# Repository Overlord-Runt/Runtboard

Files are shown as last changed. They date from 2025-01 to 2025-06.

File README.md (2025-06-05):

# Runtboard - The custom keyboard made by Taran Mittal/Overlord Runt
\
\
\
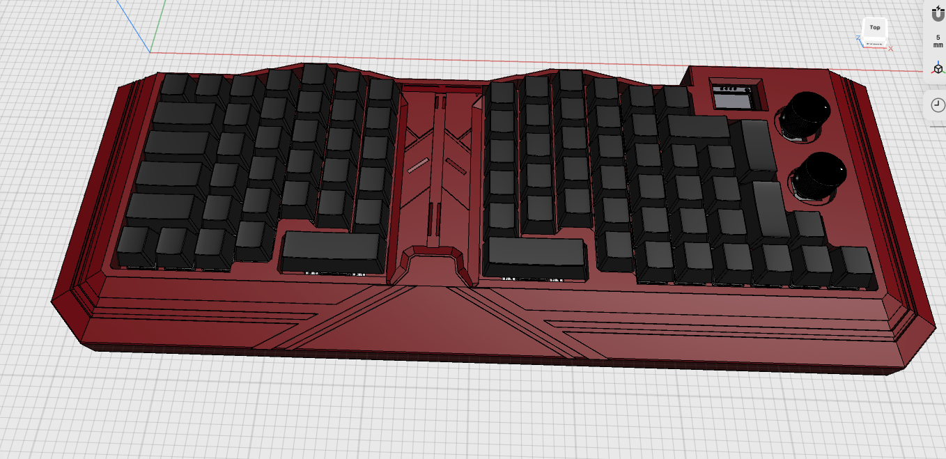
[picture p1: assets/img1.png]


## What this is
The Runtboard is a custom keyboard that I designed and coded. It has 83 keys, 2 encoders, 17 LEDs, and an OLED SSD1306 screen. I designed it to have a split keyboard style with keys split down the middle but intentionally left it stuck together to have easier firmware.\
\
I spent a total of rougly 70 hours on this project, from intial designs, pcb, case, and finally firmware. Before reaching this final design, I went through about 3 different variations going back and forth with the pcb and case.\
The Runtboard has 2 layers, one with your regular keyboard layout and one that changes the functions of the encoders. I hope you like the design and you are free to make it yourself if you have a big enough 3d printer.

## Schematic
### Here are the images for my schematic
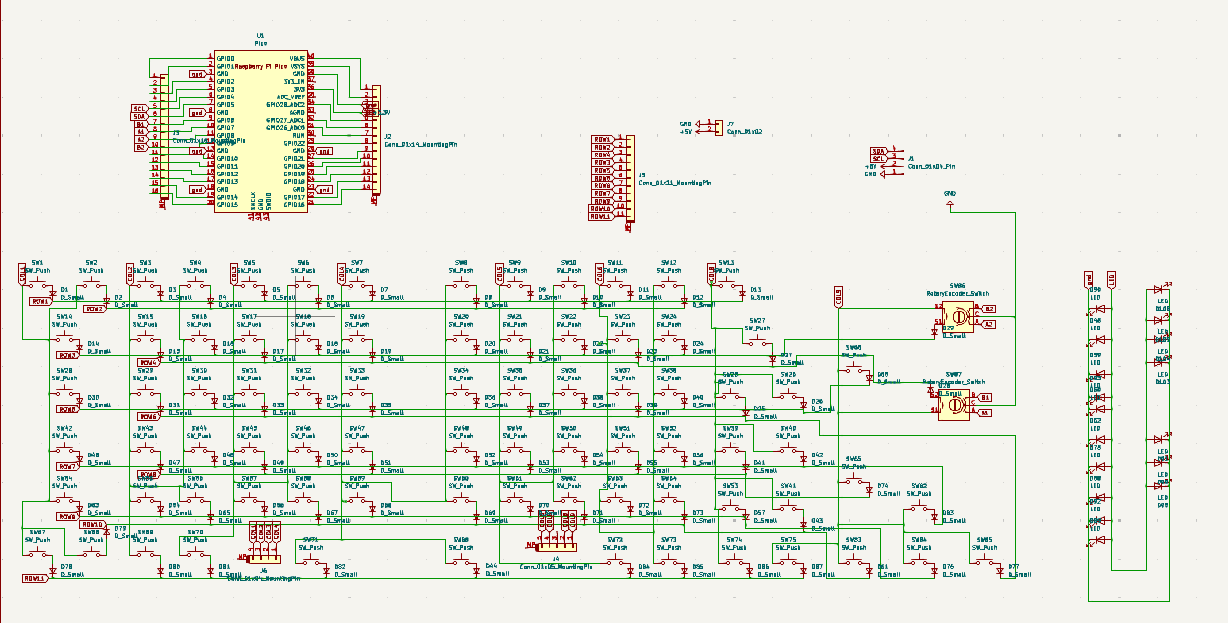
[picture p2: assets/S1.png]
\
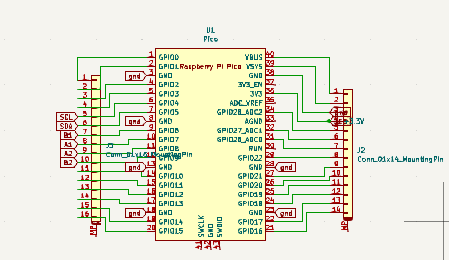
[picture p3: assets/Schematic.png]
\
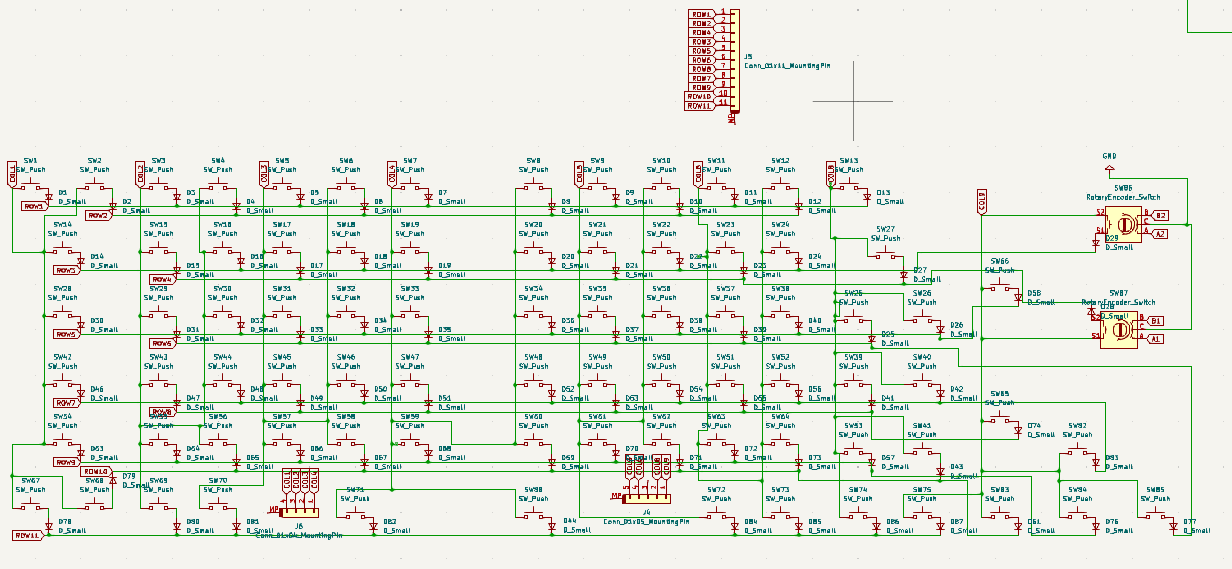
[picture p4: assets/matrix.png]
\
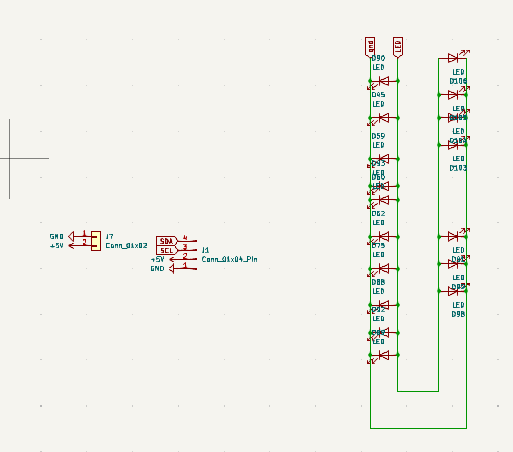
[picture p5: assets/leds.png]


The header pins are there to make it easier for my wires to reach the pico without having to do funny stuff with the routing and microcontroller. It in a way gives me a third layer to use for connections, which made my life way easier when designing this board.

### The Matrix
You may notice that my matrix looks a bit funny. This is because I overcomplicated it in order to give myself an extra 2 pins to use. By removing 8 columns and adding 6 rows, I gave myself an extra 2 pins that I used to add an extra encoder.

## PCB
### Here are images for my pcb
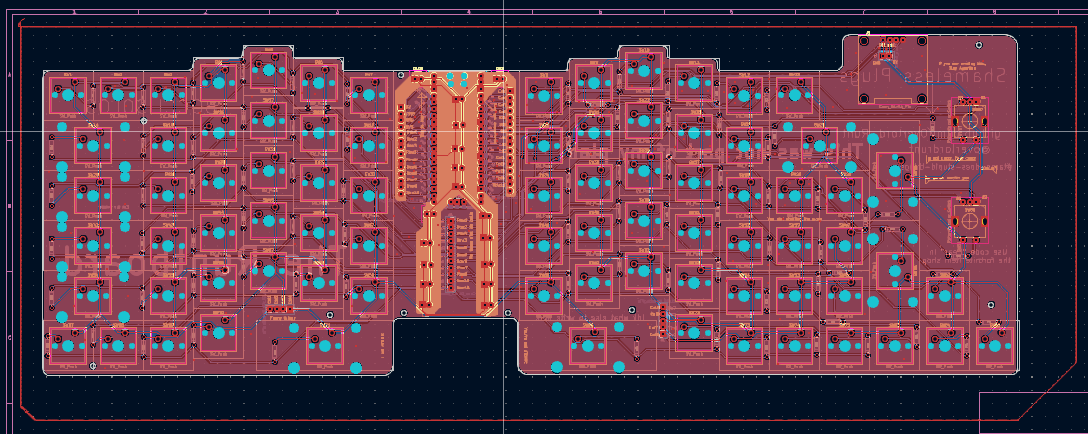
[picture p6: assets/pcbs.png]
\
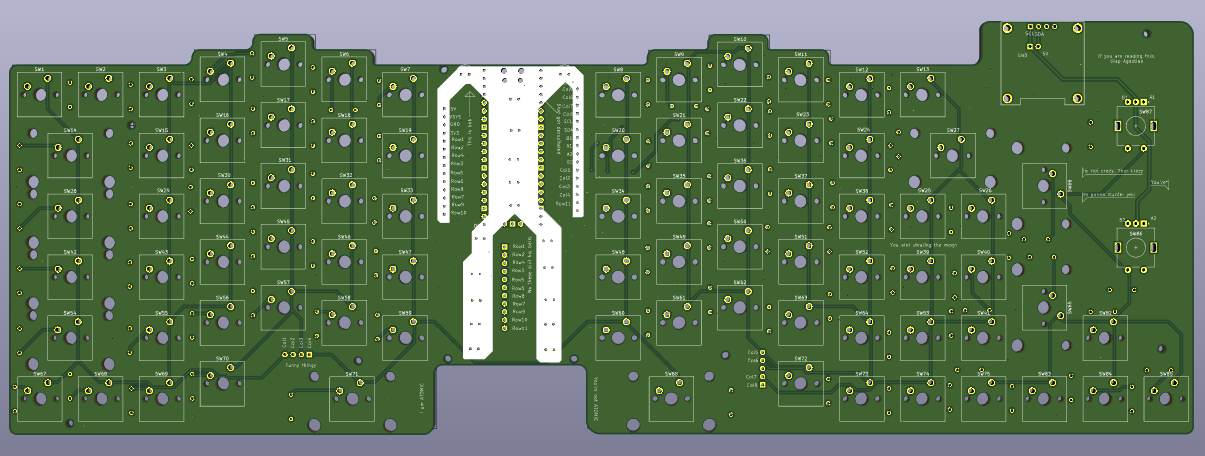
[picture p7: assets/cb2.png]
\
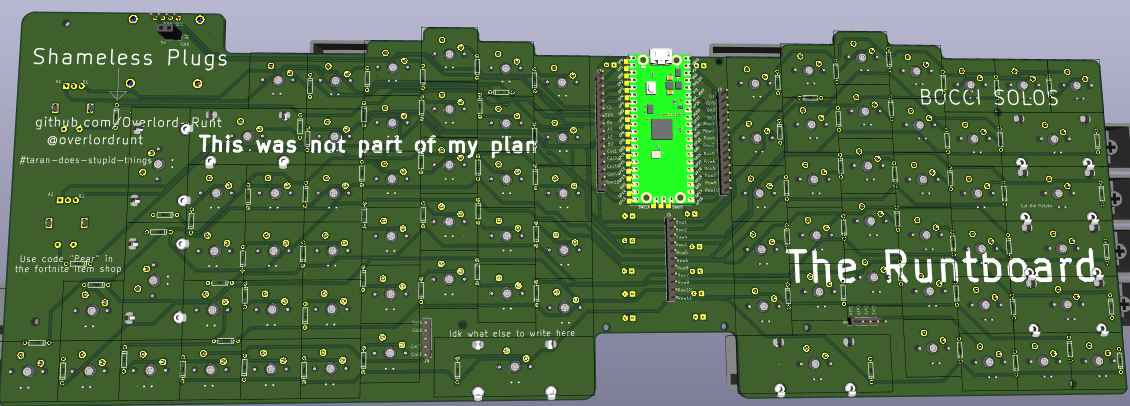
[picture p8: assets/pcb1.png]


This is what my pcb looks like. It has a basic silkscreen but i drew all of it on kicad no figma or anything.

### Silkscreen Stuff
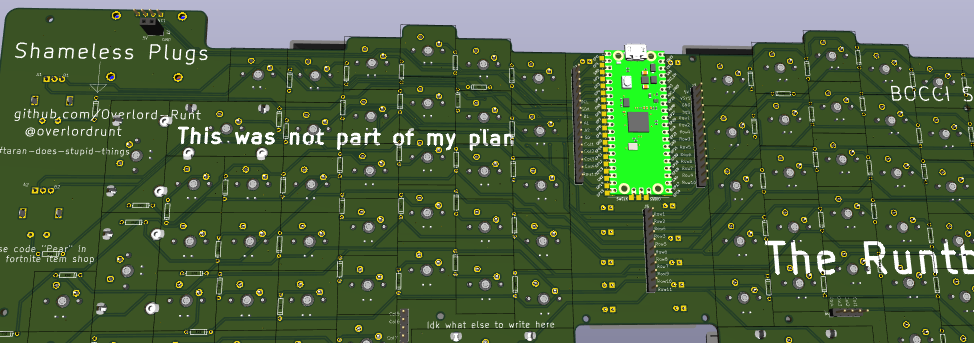
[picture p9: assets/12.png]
\
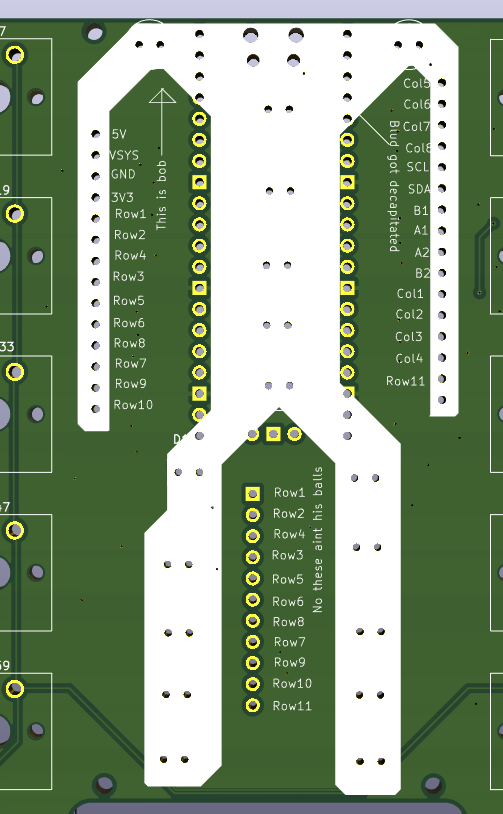
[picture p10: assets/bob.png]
\
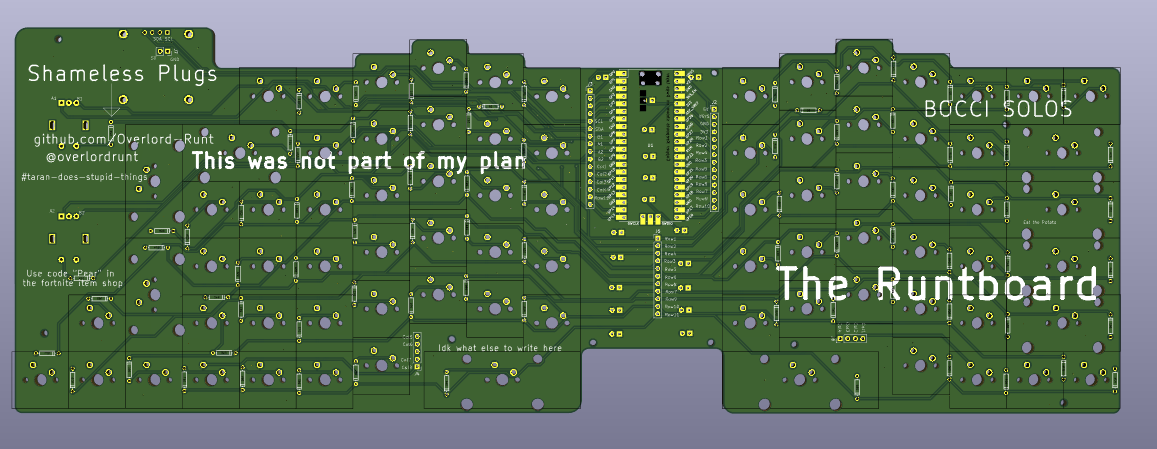
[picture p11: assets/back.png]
\
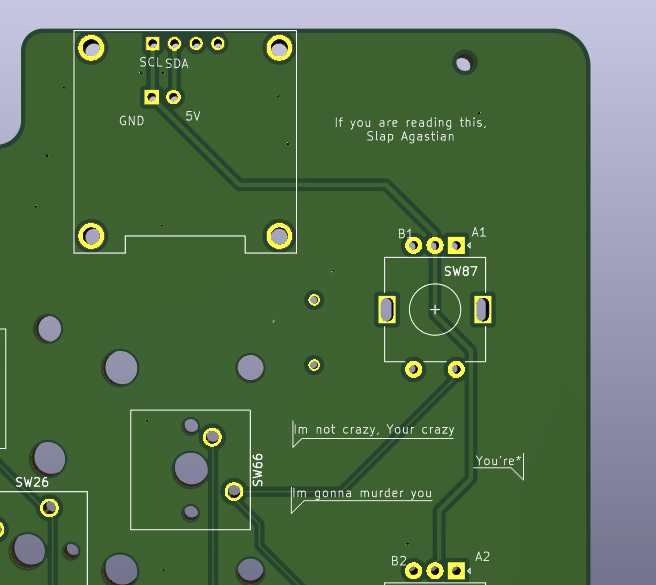
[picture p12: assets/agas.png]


On my silkscreen i have bob, the decapitated stick figure. I also have a bunch of anime references and some plugs of my socials and stuff. You should join #taran-does-stupid-things btw. its super cool. run /Darren in slack to join

## Case
I spent a lot of time designing my case(upward of 40 hours) and hope you like the design.

first\
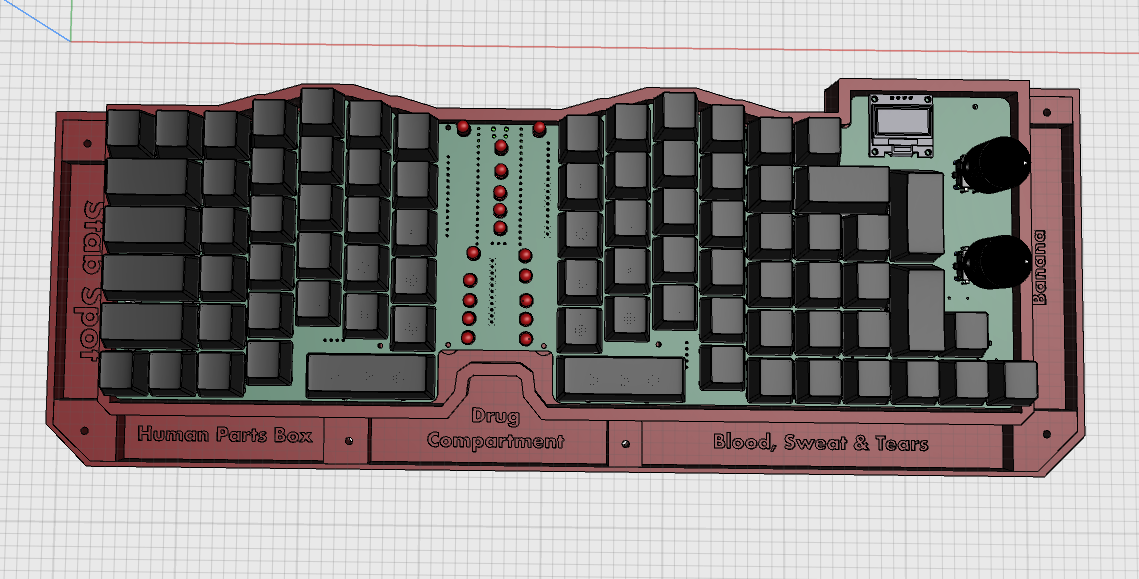
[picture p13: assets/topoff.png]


## Resources used:
Joe scotto Youtube channel\
Qmk Guides\
Ai03 plate generator\
keyboard layout editor

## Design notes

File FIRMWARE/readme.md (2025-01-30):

# handwired/runtboard

handwired/runtboard

*A short description of the keyboard/project*

* Keyboard Maintainer: [Taran Mittal](https://github.com/Overlord-Runt)
* Hardware Supported: *The PCBs, controllers supported*
* Hardware Availability: *Links to where you can find this hardware*

Make example for this keyboard (after setting up your build environment):

    make handwired/runtboard:default

Flashing example for this keyboard:

    make handwired/runtboard:default:flash

See the [build environment setup](https://docs.qmk.fm/#/getting_started_build_tools) and the [make instructions](https://docs.qmk.fm/#/getting_started_make_guide) for more information. Brand new to QMK? Start with our [Complete Newbs Guide](https://docs.qmk.fm/#/newbs).

## Bootloader

Enter the bootloader in 3 ways:

* **Bootmagic reset**: Hold down the key at (0,0) in the matrix (usually the top left key or Escape) and plug in the keyboard
* **Physical reset button**: Briefly press the button on the back of the PCB - some may have pads you must short instead
* **Keycode in layout**: Press the key mapped to `QK_BOOT` if it is available

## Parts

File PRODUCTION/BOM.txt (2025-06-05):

Bill of Materials for the Runtboard

 83 Cherry MX switches - $24.35/9.36 shipping - https://www.pccasegear.com/products/63447/gateron-g-pro-3-0-red-switch-set-110-pack-keychron
 166 hotswap sockets - $5
 85 diodes - $1.82
 2 ec11 rotary encoders - $3.24
 1 ssd1306 0.96" 128x64 oled screen - self supplied
 17 Orange 5mm LEDs - $1.21
 9 MX stabilisers - $9.36 - https://www.pccasegear.com/products/58528/akko-screw-in-stabiliser-white
 1 meter of wire - self supplied
 1 Orpheus Pico
 14 M3 X D5.0 X L6.0 Heatsets - $1.01
 8 6mm M3 screws - $1.55
 6 20mm M3 screws - $2.69
 1 USBc-USBc cable
 3D printed case - 3d printed - Dark Red
 1 PCB - $22.20/13.92 shipping
 74 1.0u Keycaps - 3d printed
 7 2.0u Keycaps - 3d printed
 2 2.75u Keycaps - 3d printed
 2 Encoder knobs - 3d printed
Total - $107.21

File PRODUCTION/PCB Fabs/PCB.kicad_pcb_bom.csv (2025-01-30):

Designator | Quantity | Value | Footprint | Package | MPN | DNP | Mount_Type | Description | Sim.Device | Sim.Pins
D1, D10, D11, D12, D13, D14, D15, D16, D17, D18, D19, D2, D20, D21, D22, D23, D24, D25, D26, D27, D28, D29, D3, D30, D31, D32, D33, D34, D35, D36, D37, D38, D39, D4, D40, D41, D42, D43, D44, D46, D47, D48, D49, D5, D50, D51, D52, D53, D54, D55, D56, D57, D58, D6, D61, D63, D64, D65, D66, D67, D68, D69, D7, D70, D71, D72, D73, D74, D76, D77, D78, D79, D8, D80, D81, D82, D83, D84, D85, D86, D87, D9 | 82 | D_Small | DIODE-1N4148 |  |  |  | tht | Diode, small symbol | D | 1=K 2=A
D103, D104, D105, D106, D45, D59, D60, D62, D75, D88, D89, D90, D91, D92, D93, D98, D99 | 17 | LED | LED_D5.0mm |  |  |  | tht | Light emitting diode
J1 | 1 | Conn_01x04_Pin | MODULE_DM-OLED096-636 |  |  |  | tht | Generic connector, single row, 01x04, script generated
J2 | 1 | Conn_01x14_MountingPin | PinHeader_1x14_P2.54mm_Vertical |  |  |  | tht | Generic connectable mounting pin connector, single row, 01x14, script generated (kicad-library-utils/schlib/autogen/connector/)
J3 | 1 | Conn_01x16_MountingPin | PinHeader_1x16_P2.54mm_Vertical |  |  |  | tht | Generic connectable mounting pin connector, single row, 01x16, script generated (kicad-library-utils/schlib/autogen/connector/)
J4 | 1 | Conn_01x05_MountingPin | PinHeader_1x05_P2.54mm_Vertical |  |  |  | tht | Generic connectable mounting pin connector, single row, 01x05, script generated (kicad-library-utils/schlib/autogen/connector/)
J5 | 1 | Conn_01x11_MountingPin | PinHeader_1x11_P2.54mm_Vertical |  |  |  | tht | Generic connectable mounting pin connector, single row, 01x11, script generated (kicad-library-utils/schlib/autogen/connector/)
J6 | 1 | Conn_01x04_MountingPin | PinHeader_1x04_P2.54mm_Vertical |  |  |  | tht | Generic connectable mounting pin connector, single row, 01x04, script generated (kicad-library-utils/schlib/autogen/connector/)
J7 | 1 | Conn_01x02 | PinSocket_1x02_P2.54mm_Vertical |  |  |  | tht | Generic connector, single row, 01x02, script generated (kicad-library-utils/schlib/autogen/connector/)
SW1, SW10, SW11, SW12, SW13, SW15, SW16, SW17, SW18, SW19, SW2, SW20, SW21, SW22, SW23, SW24, SW25, SW26, SW29, SW3, SW30, SW31, SW32, SW33, SW34, SW35, SW36, SW37, SW38, SW39, SW4, SW40, SW41, SW43, SW44, SW45, SW46, SW47, SW48, SW49, SW5, SW50, SW51, SW52, SW53, SW55, SW56, SW57, SW58, SW59, SW6, SW60, SW61, SW62, SW63, SW64, SW67, SW68, SW69, SW7, SW70, SW72, SW73, SW74, SW75, SW8, SW82, SW83, SW84, SW85, SW9 | 71 | SW_Push | SW_Cherry_MX_1.00u_PCB |  |  |  | tht | Push button switch, generic, two pins
SW14, SW27, SW28, SW42, SW54, SW65, SW66 | 7 | SW_Push | SW_Cherry_MX_2.00u_PCB |  |  |  | tht | Push button switch, generic, two pins
SW71, SW88 | 2 | SW_Push | SW_Cherry_MX_2.75u_PCB |  |  |  | tht | Push button switch, generic, two pins
SW86, SW87 | 2 | RotaryEncoder_Switch | RotaryEncoder_Alps_EC11E-Switch_Vertical_H20mm |  |  |  | tht | Rotary encoder, dual channel, incremental quadrate outputs, with switch
U1 | 1 | Pico | RPi_Pico_SMD_TH |  |  |  | tht

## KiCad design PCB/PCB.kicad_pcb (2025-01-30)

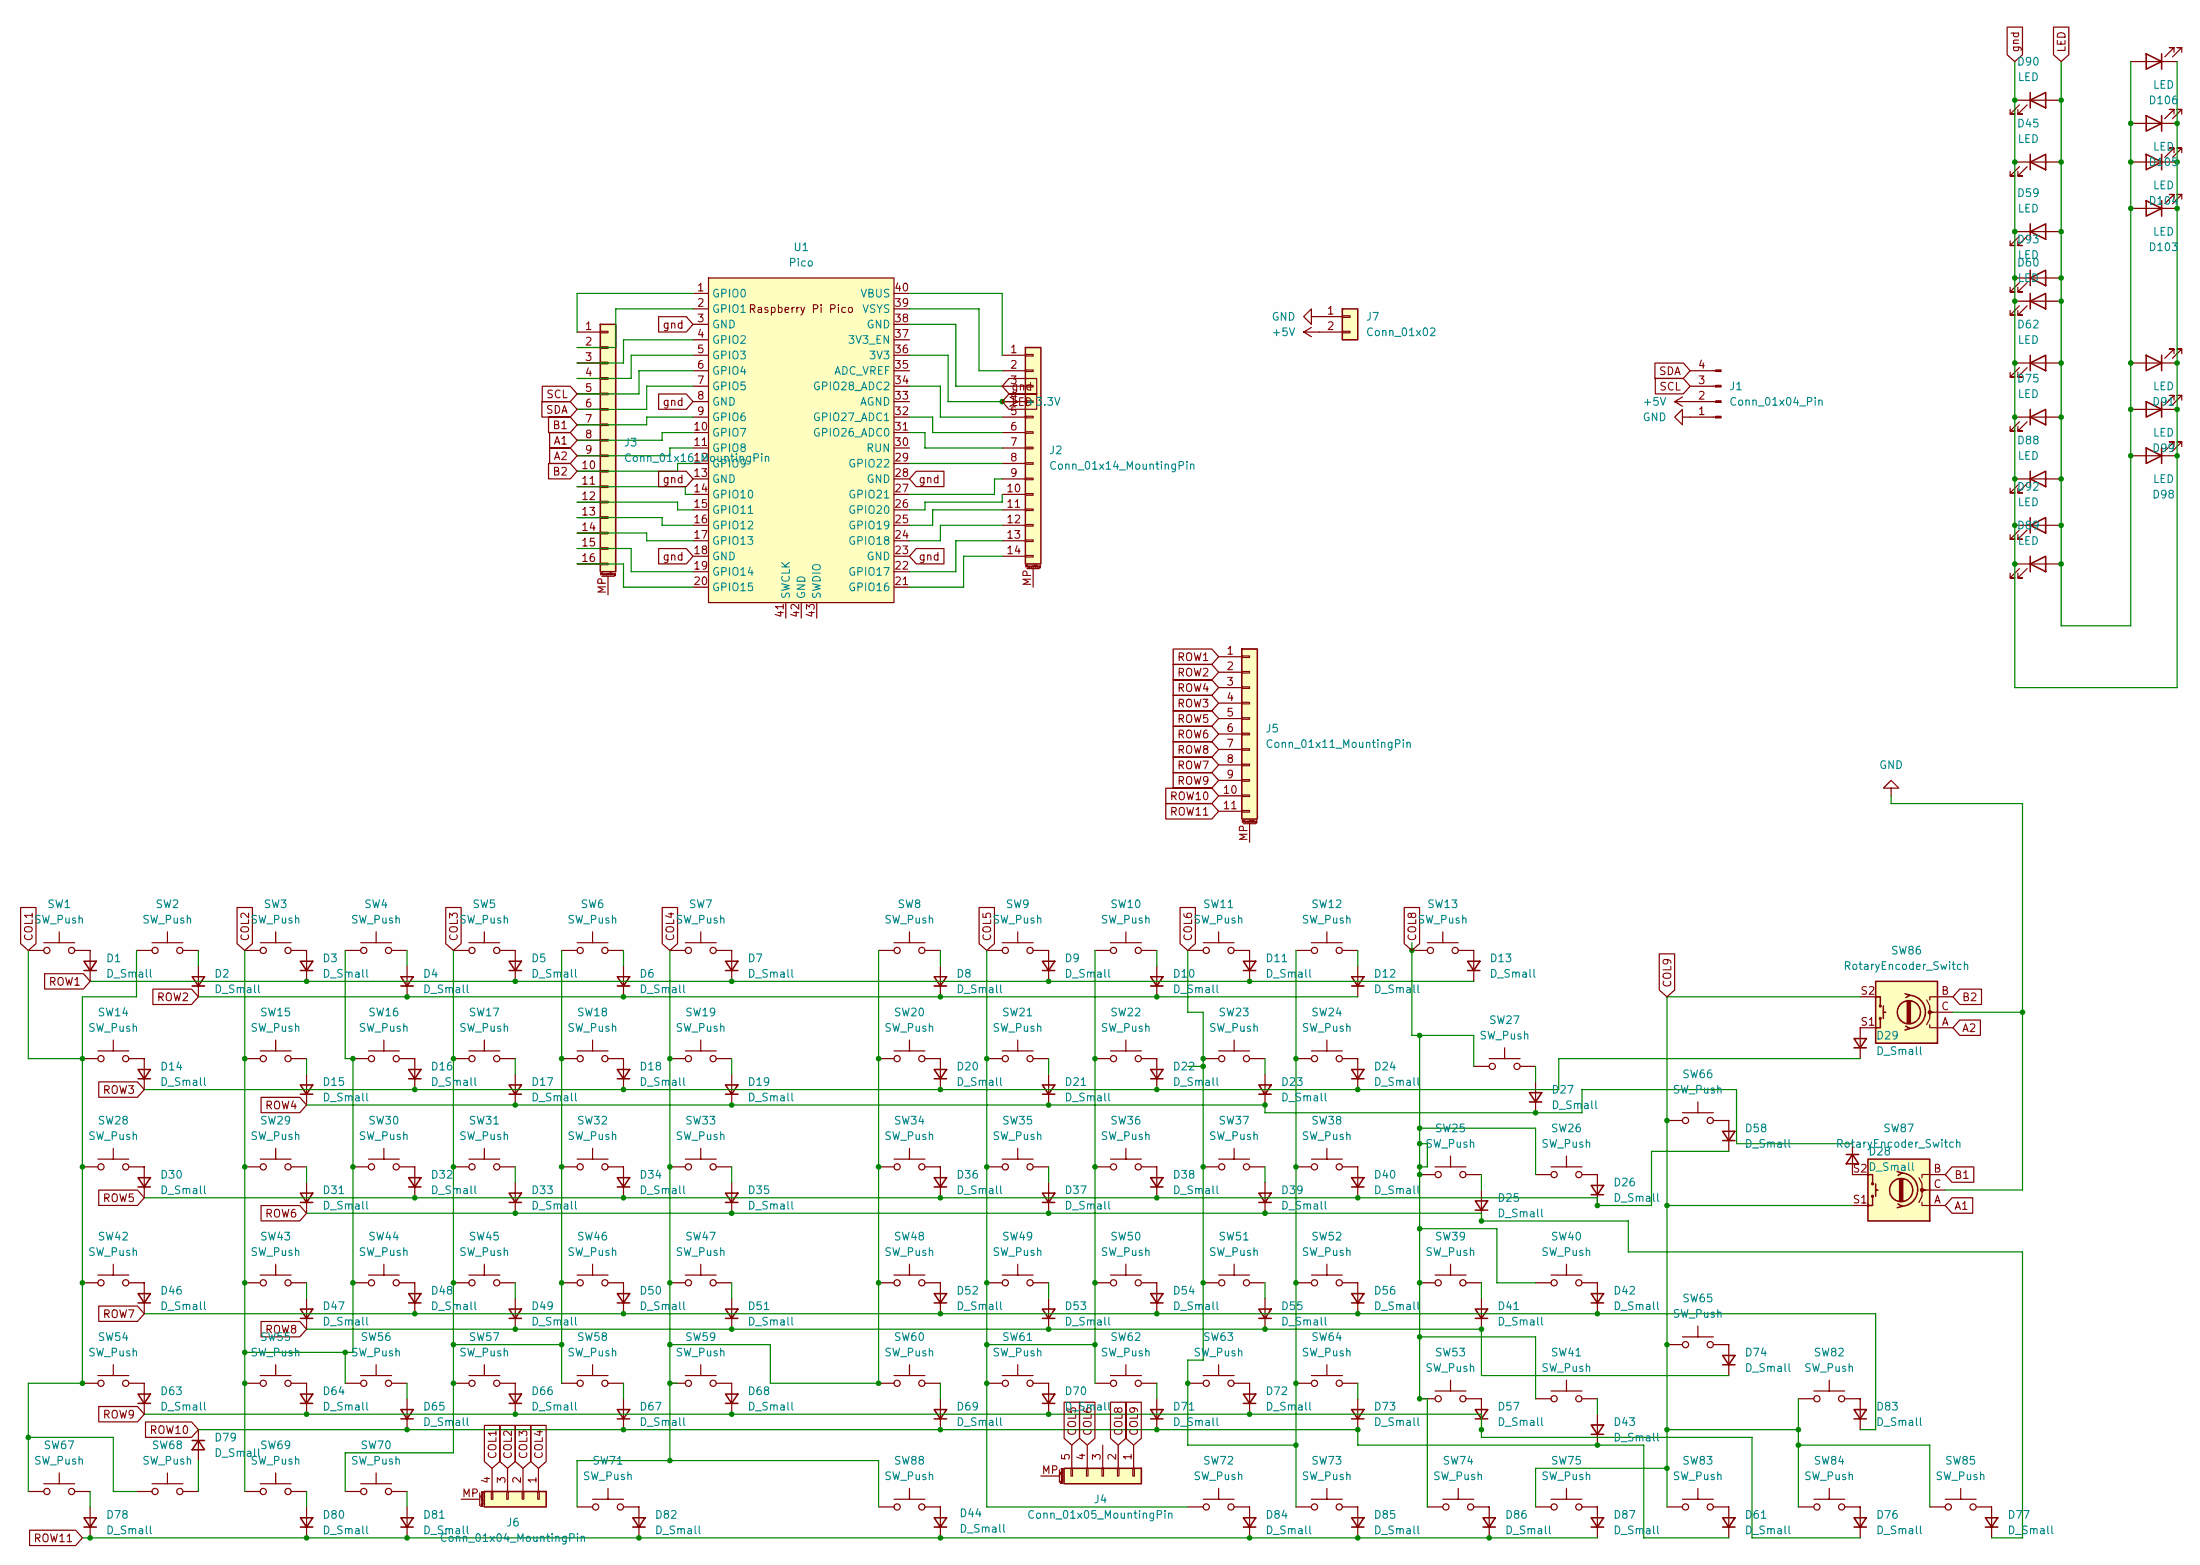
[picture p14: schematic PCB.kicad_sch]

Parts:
D1, D2, D3, D4, D5, D6, D7, D8, D9, D10, D11, D12, D13, D14, D15, D16, D17, D18, D19, D20, D21, D22, D23, D24, D25, D26, D27, D28, D29, D30, D31, D32, D33, D34, D35, D36, D37, D38, D39, D40, D41, D42, D43, D44, D46, D47, D48, D49, D50, D51, D52, D53, D54, D55, D56, D57, D58, D61, D63, D64, D65, D66, D67, D68, D69, D70, D71, D72, D73, D74, D76, D77, D78, D79, D80, D81, D82, D83, D84, D85, D86, D87: D_Small; DIODE-1N4148
D45, D59, D60, D62, D75, D88, D89, D90, D91, D92, D93, D98, D99, D103, D104, D105, D106: LED; LED_D5.0mm
J1: Conn_01x04_Pin; MODULE_DM-OLED096-636
J2: Conn_01x14_MountingPin; PinHeader_1x14_P2.54mm_Vertical
J3: Conn_01x16_MountingPin; PinHeader_1x16_P2.54mm_Vertical
J4: Conn_01x05_MountingPin; PinHeader_1x05_P2.54mm_Vertical
J5: Conn_01x11_MountingPin; PinHeader_1x11_P2.54mm_Vertical
J6: Conn_01x04_MountingPin; PinHeader_1x04_P2.54mm_Vertical
J7: Conn_01x02; PinSocket_1x02_P2.54mm_Vertical
SW1, SW2, SW3, SW4, SW5, SW6, SW7, SW8, SW9, SW10, SW11, SW12, SW13, SW15, SW16, SW17, SW18, SW19, SW20, SW21, SW22, SW23, SW24, SW25, SW26, SW29, SW30, SW31, SW32, SW33, SW34, SW35, SW36, SW37, SW38, SW39, SW40, SW41, SW43, SW44, SW45, SW46, SW47, SW48, SW49, SW50, SW51, SW52, SW53, SW55, SW56, SW57, SW58, SW59, SW60, SW61, SW62, SW63, SW64, SW67, SW68, SW69, SW70, SW72, SW73, SW74, SW75, SW82, SW83, SW84, SW85: SW_Push; SW_Cherry_MX_1.00u_PCB
SW14, SW27, SW28, SW42, SW54, SW65, SW66: SW_Push; SW_Cherry_MX_2.00u_PCB
SW71, SW88: SW_Push; SW_Cherry_MX_2.75u_PCB
SW86, SW87: RotaryEncoder_Switch; RotaryEncoder_Alps_EC11E-Switch_Vertical_H20mm
U1: Pico; RPi_Pico_SMD_TH

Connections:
+5V: J1.2, J7.2
A1: J3.8, SW87.A, U1.10 (GPIO7)
A2: J3.9, SW86.A, U1.11 (GPIO8)
B1: J3.7, SW87.B, U1.9 (GPIO6)
B2: J3.10, SW86.B, U1.12 (GPIO9)
COL1: J6.4, SW1.1, SW2.1, SW14.1, SW28.1, SW42.1, SW54.1, SW67.1, SW68.1
COL2: J6.3, SW3.1, SW4.1, SW15.1, SW16.1, SW29.1, SW30.1, SW43.1, SW44.1, SW55.1, SW56.1, SW69.1
COL3: J6.2, SW5.1, SW6.1, SW17.1, SW18.1, SW31.1, SW32.1, SW45.1, SW46.1, SW57.1, SW58.1, SW70.1
COL4: J6.1, SW7.1, SW8.1, SW19.1, SW20.1, SW33.1, SW34.1, SW47.1, SW48.1, SW59.1, SW60.1, SW71.1, SW88.1
COL5: J4.5, SW9.1, SW10.1, SW21.1, SW22.1, SW35.1, SW36.1, SW49.1, SW50.1, SW61.1, SW62.1, SW72.1
COL6: J4.4, SW11.1, SW12.1, SW23.1, SW24.1, SW37.1, SW38.1, SW51.1, SW52.1, SW63.1, SW64.1, SW73.1
COL8: J4.2, SW13.1, SW25.1, SW26.1, SW27.1, SW39.1, SW40.1, SW41.1, SW53.1, SW74.1
COL9: J4.1, SW65.1, SW66.1, SW75.1, SW82.1, SW83.1, SW84.1, SW85.1, SW86.S2, SW87.S1
GND: J1.1, J7.1, SW86.C, SW87.C
LED: D45.2 (A), D59.2 (A), D60.2 (A), D62.2 (A), D75.2 (A), D88.2 (A), D89.2 (A), D90.2 (A), D91.2 (A), D92.2 (A), D93.2 (A), D98.2 (A), D99.2 (A), D103.2 (A), D104.2 (A), D105.2 (A), D106.2 (A), J2.4, U1.36 (3V3)
unnamed: D1.A, SW1.2
unnamed: D2.A, SW2.2
unnamed: D3.A, SW3.2
unnamed: D4.A, SW4.2
unnamed: D5.A, SW5.2
unnamed: D6.A, SW6.2
unnamed: D7.A, SW7.2
unnamed: D8.A, SW8.2
unnamed: D9.A, SW9.2
unnamed: D10.A, SW10.2
unnamed: D11.A, SW11.2
unnamed: D12.A, SW12.2
unnamed: D13.A, SW13.2
unnamed: D14.A, SW14.2
unnamed: D15.A, SW15.2
unnamed: D16.A, SW16.2
unnamed: D17.A, SW17.2
unnamed: D18.A, SW18.2
unnamed: D19.A, SW19.2
unnamed: D20.A, SW20.2
unnamed: D21.A, SW21.2
unnamed: D22.A, SW22.2
unnamed: D23.A, SW23.2
unnamed: D24.A, SW24.2
unnamed: D25.A, SW25.2
unnamed: D26.A, SW26.2
unnamed: D27.A, SW27.2
unnamed: D28.A, SW87.S2
unnamed: D29.A, SW86.S1
unnamed: D30.A, SW28.2
unnamed: D31.A, SW29.2
unnamed: D32.A, SW30.2
unnamed: D33.A, SW31.2
unnamed: D34.A, SW32.2
unnamed: D35.A, SW33.2
unnamed: D36.A, SW34.2
unnamed: D37.A, SW35.2
unnamed: D38.A, SW36.2
unnamed: D39.A, SW37.2
unnamed: D40.A, SW38.2
unnamed: D41.A, SW39.2
unnamed: D42.A, SW40.2
unnamed: D43.A, SW41.2
unnamed: D44.A, SW88.2
unnamed: D46.A, SW42.2
unnamed: D47.A, SW43.2
unnamed: D48.A, SW44.2
unnamed: D49.A, SW45.2
unnamed: D50.A, SW46.2
unnamed: D51.A, SW47.2
unnamed: D52.A, SW48.2
unnamed: D53.A, SW49.2
unnamed: D54.A, SW50.2
unnamed: D55.A, SW51.2
unnamed: D56.A, SW52.2
unnamed: D57.A, SW53.2
unnamed: D58.A, SW66.2
unnamed: D61.A, SW83.2
unnamed: D63.A, SW54.2
unnamed: D64.A, SW55.2
unnamed: D65.A, SW56.2
unnamed: D66.A, SW57.2
unnamed: D67.A, SW58.2
unnamed: D68.A, SW59.2
unnamed: D69.A, SW60.2
unnamed: D70.A, SW61.2
unnamed: D71.A, SW62.2
unnamed: D72.A, SW63.2
unnamed: D73.A, SW64.2
unnamed: D74.A, SW65.2
unnamed: D76.A, SW84.2
unnamed: D77.A, SW85.2
unnamed: D78.A, SW67.2
unnamed: D79.A, SW68.2
unnamed: D80.A, SW69.2
unnamed: D81.A, SW70.2
unnamed: D82.A, SW71.2
unnamed: D83.A, SW82.2
unnamed: D84.A, SW72.2
unnamed: D85.A, SW73.2
unnamed: D86.A, SW74.2
unnamed: D87.A, SW75.2
unnamed: J2.1, U1.40 (VBUS)
unnamed: J2.2, U1.39 (VSYS)
unnamed: J2.5, U1.34 (GPIO28_ADC2)
unnamed: J2.6, U1.32 (GPIO27_ADC1)
unnamed: J2.7, U1.31 (GPIO26_ADC0)
unnamed: J2.8, U1.29 (GPIO22)
unnamed: J2.9, U1.27 (GPIO21)
unnamed: J2.10, U1.26 (GPIO20)
unnamed: J2.11, U1.25 (GPIO19)
unnamed: J2.12, U1.24 (GPIO18)
unnamed: J2.13, U1.22 (GPIO17)
unnamed: J2.14, U1.21 (GPIO16)
unnamed: J3.1, U1.1 (GPIO0)
unnamed: J3.2, U1.2 (GPIO1)
unnamed: J3.3, U1.4 (GPIO2)
unnamed: J3.4, U1.5 (GPIO3)
unnamed: J3.11, U1.14 (GPIO10)
unnamed: J3.12, U1.15 (GPIO11)
unnamed: J3.13, U1.16 (GPIO12)
unnamed: J3.14, U1.17 (GPIO13)
unnamed: J3.15, U1.19 (GPIO14)
unnamed: J3.16, U1.20 (GPIO15)
ROW1: D1.K, D3.K, D5.K, D7.K, D9.K, D11.K, D13.K, J5.1
ROW2: D2.K, D4.K, D6.K, D8.K, D10.K, D12.K, J5.2
ROW3: D14.K, D16.K, D18.K, D20.K, D22.K, D24.K, D29.K, J5.4
ROW4: D15.K, D17.K, D19.K, D21.K, D23.K, D27.K, D28.K, J5.3
ROW5: D26.K, D30.K, D32.K, D34.K, D36.K, D38.K, D40.K, D58.K, J5.5
ROW6: D25.K, D31.K, D33.K, D35.K, D37.K, D39.K, D77.K, J5.6
ROW7: D42.K, D46.K, D48.K, D50.K, D52.K, D54.K, D56.K, D83.K, J5.8
ROW8: D41.K, D47.K, D49.K, D51.K, D53.K, D55.K, D74.K, J5.7
ROW9: D57.K, D63.K, D64.K, D66.K, D68.K, D70.K, D72.K, D76.K, J5.9
ROW10: D43.K, D61.K, D65.K, D67.K, D69.K, D71.K, D73.K, D79.K, J5.10
ROW11: D44.K, D78.K, D80.K, D81.K, D82.K, D84.K, D85.K, D86.K, D87.K, J5.11
SCL: J1.3, J3.5, U1.6 (GPIO4)
SDA: J1.4, J3.6, U1.7 (GPIO5)
gnd: D45.1 (K), D59.1 (K), D60.1 (K), D62.1 (K), D75.1 (K), D88.1 (K), D89.1 (K), D90.1 (K), D91.1 (K), D92.1 (K), D93.1 (K), D98.1 (K), D99.1 (K), D103.1 (K), D104.1 (K), D105.1 (K), D106.1 (K), J2.3, U1.3 (GND), U1.8 (GND), U1.13 (GND), U1.18 (GND), U1.23 (GND), U1.28 (GND), U1.38 (GND)

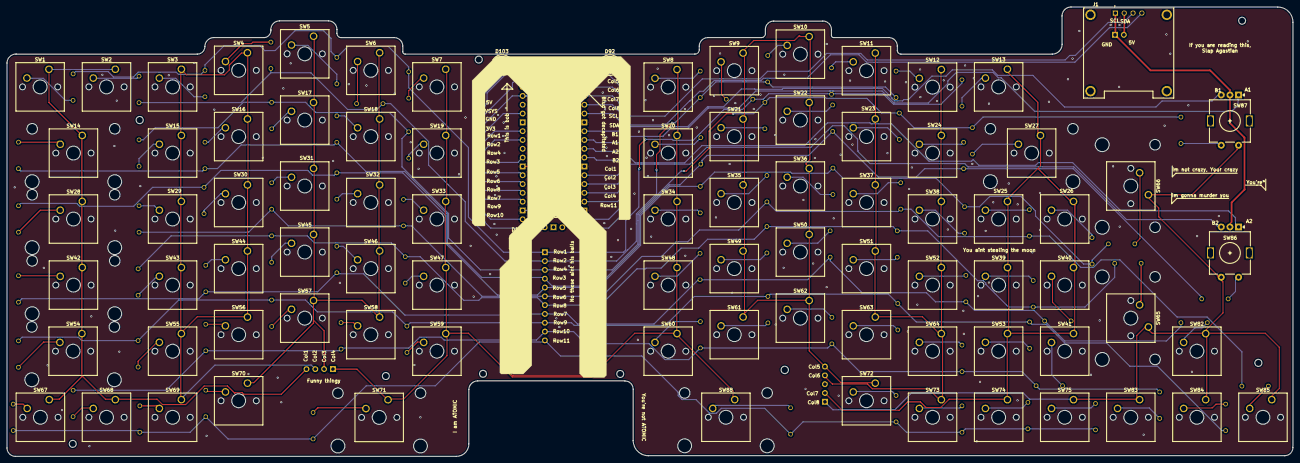
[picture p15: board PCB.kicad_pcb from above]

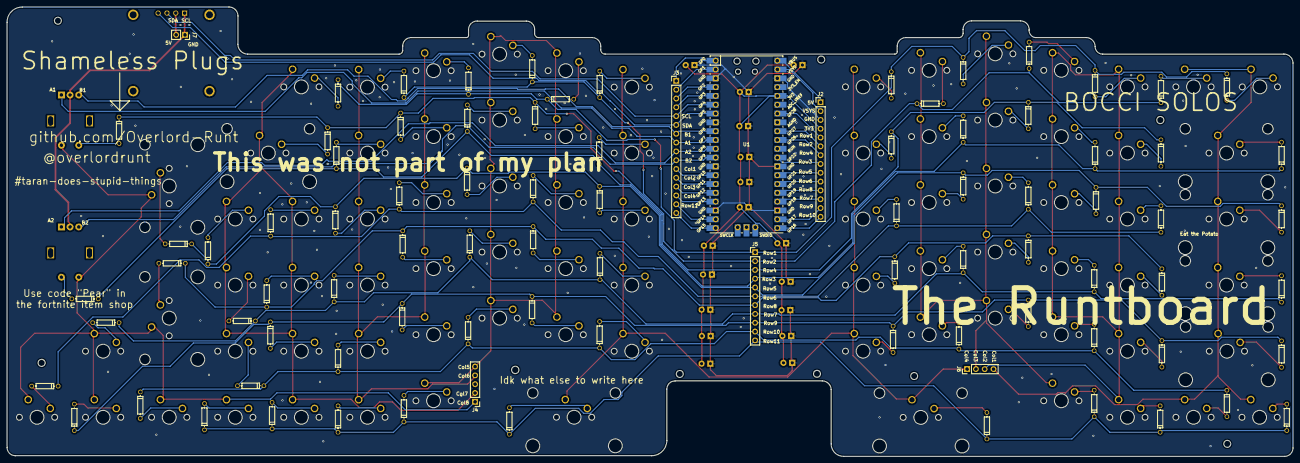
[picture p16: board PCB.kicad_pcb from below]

Board: 2 copper layers, 370.7 x 129.5 mm, 189 parts (89 on the bottom side), 133 nets.

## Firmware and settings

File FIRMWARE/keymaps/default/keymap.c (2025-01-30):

#include QMK_KEYBOARD_H

#if defined(ENCODER_MAP_ENABLE)
const uint16_t PROGMEM encoder_map[][2][2] = {
    [0] =  { ENCODER_CCW_CW(KC_VOLD, KC_VOLU), ENCODER_CCW_CW(KC_BRIU, KC_BRID)},
	[1] =  { ENCODER_CCW_CW(QK_MOUSE_CURSOR_UP, QK_MOUSE_CURSOR_DOWN), ENCODER_CCW_CW(QK_MOUSE_CURSOR_LEFT, QK_MOUSE_CURSOR_RIGHT)}
};
#endif


const uint16_t PROGMEM keymaps[][MATRIX_ROWS][MATRIX_COLS] = {

    [0] = LAYOUT(
        KC_ESC,  KC_F2,   KC_F4,   KC_F6,   KC_F8, KC_F10,   KC_F12,   XXXXXXX,
        KC_F1,   KC_F3,   KC_F5,   KC_F7, KC_F9,   KC_F11,   XXXXXXX,   XXXXXXX,
        KC_TILD,   KC_2,   KC_4,   KC_6, KC_8,   KC_0,   XXXXXXX,   KC_MUTE,
        XXXXXXX,   KC_1,   KC_3,   KC_5, KC_7,   KC_9,   KC_BSPC,   KC_DEL,
        KC_TAB,   KC_W,   KC_R,   KC_Y, KC_I,   KC_P,   KC_EQL,   KC_ENT,
        XXXXXXX,  KC_Q,   KC_E,   KC_T, KC_U,   KC_O,    KC_MINS,   KC_RIGHT,
        KC_CAPS,   KC_S,   KC_F,   KC_H, KC_K,   KC_SCLN,   KC_RBRC,   KC_UP,
        XXXXXXX,   KC_A,   KC_D,   KC_G, KC_J,   KC_L,   KC_LBRC,   KC_RSFT,
        KC_LSFT,   KC_X,  KC_V,    KC_N, KC_COMM,   KC_SLSH,   KC_QUOT,   KC_DOWN,
        KC_LALT,   KC_Z,   KC_C,   KC_B, KC_M,   KC_DOT,   KC_BSLS,   KC_LEFT,
        KC_LCTL,   KC_LGUI,   TG(1),   KC_SPC, XXXXXXX,   KC_RGUI,   KC_RALT,   KC_RCTL
    ),
	[1] = LAYOUT(
        KC_ESC,  KC_F2,   KC_F4,   KC_F6,   KC_F8, KC_F10,   KC_F12,   XXXXXXX,
        KC_F1,   KC_F3,   KC_F5,   KC_F7, KC_F9,   KC_F11,   XXXXXXX,   XXXXXXX,
        KC_TILD,   KC_2,   KC_4,   KC_6, KC_8,   KC_0,   XXXXXXX,   KC_MUTE,
        XXXXXXX,   KC_1,   KC_3,   KC_5, KC_7,   KC_9,   KC_BSPC,   KC_DEL,
        KC_TAB,   KC_W,   KC_R,   KC_Y, KC_I,   KC_P,   KC_EQL,   KC_ENT,
        XXXXXXX,  KC_Q,   KC_E,   KC_T, KC_U,   KC_O,    KC_MINS,   KC_RIGHT,
        KC_CAPS,   KC_S,   KC_F,   KC_H, KC_K,   KC_SCLN,   KC_RBRC,   KC_UP,
        XXXXXXX,   KC_A,   KC_D,   KC_G, KC_J,   KC_L,   KC_LBRC,   KC_RSFT,
        KC_LSFT,   KC_X,  KC_V,    KC_N, KC_COMM,   KC_SLSH,   KC_QUOT,   KC_DOWN,
        KC_LALT,   KC_Z,   KC_C,   KC_B, KC_M,   KC_DOT,   KC_BSLS,   KC_LEFT,
        KC_LCTL,   KC_LGUI,   TG(1),   KC_SPC, XXXXXXX,   KC_RGUI,   KC_RALT,   KC_RCTL
    ),

};



#ifdef OLED_ENABLE

#define FRAME_DURATION 100
const uint16_t frame_sizes[5] = {1040, 1040, 1040, 1040, 1040};

uint32_t timer = 0;
uint8_t current_frame = 0;

static void render_animation(void) {
    // 'frame_0_delay-0', 128x64px
static unsigned char epd_bitmap_frame_0_delay_0 [] PROGMEM = {
	0xff, 0xff, 0xff, 0xff, 0xff, 0xff, 0xff, 0xff, 0xff, 0xff, 0xff, 0xff, 0xff, 0xff, 0xff, 0xff, 
	0xff, 0xff, 0xff, 0xff, 0xff, 0xff, 0xff, 0xff, 0xff, 0xff, 0xff, 0xff, 0xff, 0xff, 0xff, 0xff, 
	0xff, 0xff, 0xff, 0xff, 0xff, 0xff, 0xff, 0xff, 0xff, 0xff, 0xff, 0xff, 0xff, 0xff, 0xff, 0xff, 
	0xff, 0xff, 0xff, 0xff, 0xff, 0xff, 0xff, 0xff, 0xff, 0xff, 0xff, 0xff, 0xff, 0xff, 0xff, 0xff, 
	0xff, 0xff, 0xff, 0xff, 0xff, 0xff, 0xff, 0xff, 0xff, 0xff, 0xff, 0xff, 0xff, 0xff, 0xff, 0xff, 
	0xff, 0xff, 0xff, 0xff, 0xff, 0xfc, 0x7f, 0xff, 0xff, 0xff, 0xff, 0xff, 0xff, 0xff, 0xff, 0xff, 
	0xff, 0xff, 0xff, 0xff, 0xff, 0xfc, 0x7f, 0xff, 0xff, 0xff, 0xff, 0xff, 0xff, 0xff, 0xff, 0xff, 
	0xff, 0xff, 0xff, 0xff, 0xff, 0xfc, 0xff, 0xff, 0xff, 0xff, 0xff, 0xff, 0xff, 0xff, 0xff, 0xff, 
	0xff, 0xff, 0xff, 0xff, 0xff, 0xf3, 0x9f, 0xff, 0xff, 0xff, 0xfe, 0x3f, 0xff, 0xff, 0xff, 0xff, 
	0xff, 0xff, 0xff, 0xff, 0xff, 0xf3, 0x9f, 0xff, 0xff, 0xff, 0xfe, 0x3f, 0xff, 0xff, 0xff, 0xff, 
	0xff, 0xff, 0xff, 0xff, 0xff, 0x9f, 0xe3, 0xff, 0xff, 0xff, 0xf9, 0xcf, 0xff, 0xff, 0xff, 0xff, 
	0xff, 0xff, 0xff, 0xff, 0xff, 0x9f, 0xe3, 0xff, 0xff, 0xff, 0xf9, 0xcf, 0xff, 0xff, 0xff, 0xff, 
	0xff, 0xff, 0xff, 0xff, 0xff, 0x9f, 0xe3, 0xff, 0xff, 0xff, 0xf9, 0xcf, 0xff, 0xff, 0xff, 0xff, 
	0xff, 0xff, 0xff, 0xff, 0xfc, 0x7f, 0xfc, 0x00, 0x00, 0xff, 0xcf, 0xcf, 0xff, 0xff, 0xff, 0xff, 
	0xff, 0xff, 0xff, 0xff, 0xfc, 0x7f, 0xfc, 0x00, 0x00, 0xff, 0xcf, 0xcf, 0xff, 0xff, 0xff, 0xff, 
	0xff, 0xff, 0xff, 0xff, 0xfc, 0x7f, 0xff, 0xff, 0xff, 0x00, 0x3f, 0xcf, 0xff, 0xff, 0xff, 0xff, 
	0xff, 0xff, 0xff, 0xff, 0xfc, 0x7f, 0xff, 0xff, 0xff, 0x00, 0x3f, 0xcf, 0xff, 0xff, 0xff, 0xff, 
	0xff, 0xff, 0xff, 0xff, 0xfc, 0x7f, 0xff, 0xff, 0xff, 0x00, 0x3f, 0xcf, 0xff, 0xff, 0xff, 0xff, 
	0xff, 0xff, 0xff, 0xff, 0xf3, 0xff, 0xff, 0xff, 0xff, 0xff, 0xff, 0xf1, 0xff, 0xff, 0xff, 0xff, 
	0xff, 0xff, 0xff, 0xff, 0xf3, 0xff, 0xff, 0xff, 0xff, 0xff, 0xff, 0xf1, 0xff, 0xff, 0xff, 0xff, 
	0xff, 0xff, 0xff, 0xff, 0xf3, 0xff, 0xff, 0xff, 0xff, 0xff, 0xff, 0xf1, 0xff, 0xff, 0xff, 0xff, 
	0xff, 0xff, 0xff, 0xff, 0xf3, 0xff, 0xff, 0xff, 0xff, 0xff, 0xff, 0xf1, 0xff, 0xff, 0xff, 0xff, 
	0xff, 0xff, 0xff, 0xff, 0xf3, 0xff, 0xff, 0xff, 0xff, 0xff, 0xff, 0xf1, 0xff, 0xff, 0xff, 0xff, 
	0xff, 0xff, 0xfe, 0x0f, 0x8f, 0xff, 0xff, 0xff, 0xff, 0xfe, 0x0f, 0xf1, 0xff, 0xff, 0xff, 0xff, 
	0xff, 0xff, 0xfe, 0x0f, 0x8f, 0xff, 0xff, 0xff, 0xff, 0xfe, 0x0f, 0xf1, 0xff, 0xff, 0xff, 0xff, 
	0xff, 0xff, 0xff, 0xff, 0x8f, 0xff, 0xff, 0xff, 0xff, 0xff, 0xff, 0xff, 0xff, 0xff, 0xff, 0xff, 
	0xff, 0xff, 0xf9, 0xf1, 0x8f, 0xff, 0xff, 0xff, 0xff, 0xf9, 0xf9, 0xfe, 0x7f, 0xff, 0xff, 0xff, 
	0xff, 0xff, 0xf9, 0xf1, 0x8f, 0xff, 0xff, 0xff, 0xff, 0xf9, 0xf9, 0xfe, 0x7f, 0xff, 0xff, 0xff, 
	0xff, 0xff, 0xf9, 0xfe, 0x7f, 0x83, 0xff, 0xff, 0xf8, 0x39, 0xfe, 0x7f, 0x8f, 0xff, 0xff, 0xff, 
	0xff, 0xff, 0xf9, 0xfe, 0x7f, 0x83, 0xff, 0xff, 0xf8, 0x39, 0xfe, 0x7f, 0x8f, 0xff, 0xff, 0xff, 
	0xff, 0xff, 0xf9, 0xfe, 0x7f, 0x83, 0xff, 0xff, 0xf8, 0x39, 0xfe, 0x7f, 0xcf, 0xff, 0xff, 0xff, 
	0xff, 0xff, 0xf9, 0xff, 0x8f, 0x83, 0x9f, 0x1f, 0x38, 0x39, 0xff, 0xff, 0xf3, 0xff, 0xff, 0xff, 
	0xff, 0xff, 0xf9, 0xff, 0x8f, 0x83, 0x9f, 0x1f, 0x38, 0x39, 0xff, 0xff, 0xf3, 0xff, 0xff, 0xff, 
	0xff, 0xff, 0xfe, 0x7f, 0xff, 0xff, 0xe0, 0xe0, 0xff, 0xff, 0x3f, 0xff, 0xf3, 0xff, 0xff, 0xff, 
	0xff, 0xff, 0xfe, 0x7f, 0xff, 0xff, 0xe0, 0xe0, 0xff, 0xfe, 0x3f, 0xff, 0xf3, 0xff, 0xff, 0xff, 
	0xff, 0xff, 0xfe, 0x7f, 0xff, 0xff, 0xe0, 0xe0, 0xff, 0xff, 0x3f, 0xff, 0xf3, 0xff, 0xff, 0xff, 
	0xff, 0xff, 0xff, 0xcf, 0xff, 0xff, 0xff, 0xff, 0xff, 0xff, 0xcf, 0xff, 0xfe, 0x7f, 0xff, 0xff, 
	0xff, 0xff, 0xff, 0xcf, 0xff, 0xff, 0xff, 0xff, 0xff, 0xff, 0xcf, 0xff, 0xfe, 0x7f, 0xff, 0xff, 
	0xff, 0xff, 0xff, 0xff, 0xff, 0xff, 0xff, 0xff, 0xff, 0xff, 0xff, 0xff, 0xfe, 0x7f, 0xff, 0xff, 
	0xff, 0xff, 0xff, 0xf1, 0xff, 0xff, 0xff, 0xff, 0xff, 0xff, 0xf9, 0xff, 0xfe, 0x7f, 0xff, 0xff, 
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
};
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
